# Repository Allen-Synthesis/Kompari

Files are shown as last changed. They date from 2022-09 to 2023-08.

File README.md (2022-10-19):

one
***
# Kompari
### A comparator module for Eurorack
  
***
### Features:
- 2 ±12V inputs, each with attenuverter
- Unipolar/Bipolar output switch
- 1 ±10V output, with attenuverter

Plug any CV or audio source into one of the two inputs, and it will be compared against the other.  

The output will be high (+10V) if input A is greater than input B.  

The output will be low (-10V if set to bipolar, 0V if set to unipolar) if input B is greater than input A.  

Both inputs have an attenuverter, and are both normalled to +12V, so with only one input, the value of input B can be controlled simply using the attenuverter as a ±10V voltage source.  
***
four
***
### Easy to DIY
The module has fairly few components, and is entirely through hole. It is also 'free hardware' so you can access all the design files in this repo, and check out the [Interactive Bill of Materials here!](https://htmlpreview.github.io/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)

***
### Patch Examples

#### PWM
While the concept may seem simple, the versatility of a comparator in Eurorack is far reaching.  
For example, feeding a triangle wave input to input A will result in a square wave output of the same wave, and input B (or simply the attenuverter normalled to +12) will act as PWM to that square wave. Plug the original triangle and this new PWM square wave into a crossfader/mixer and you now have a pretty modulatable waveshaper.  
  
#### Compressor
Another more complex case would be to run an audio source through an envelope follower, then into input A. Use input B to set a maximum voltage (volume), and when the volume of the audio (envelope follower voltage) goes above this voltage, the Kompari output should trigger an envelope generator which has a negative effect on the volume of a VCA on the original audio. You now have a slightly roundabout, but fully fledged compressor! The envelope generator's attack and decay controls are the response of the compressor, the VCA's unaltered input voltage (before subtracting the envelope) is the makeup gain, and the Kompari's input B is the threshold.  
  
As you can see, it's easy to get carried away with using a comparator module such as the Kompari, and the patches you can make are only limited by your imagination!

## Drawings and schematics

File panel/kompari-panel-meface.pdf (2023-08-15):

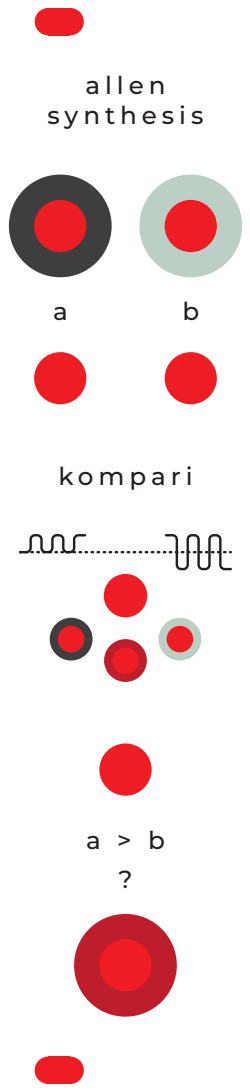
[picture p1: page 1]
kompari; allen synthesis

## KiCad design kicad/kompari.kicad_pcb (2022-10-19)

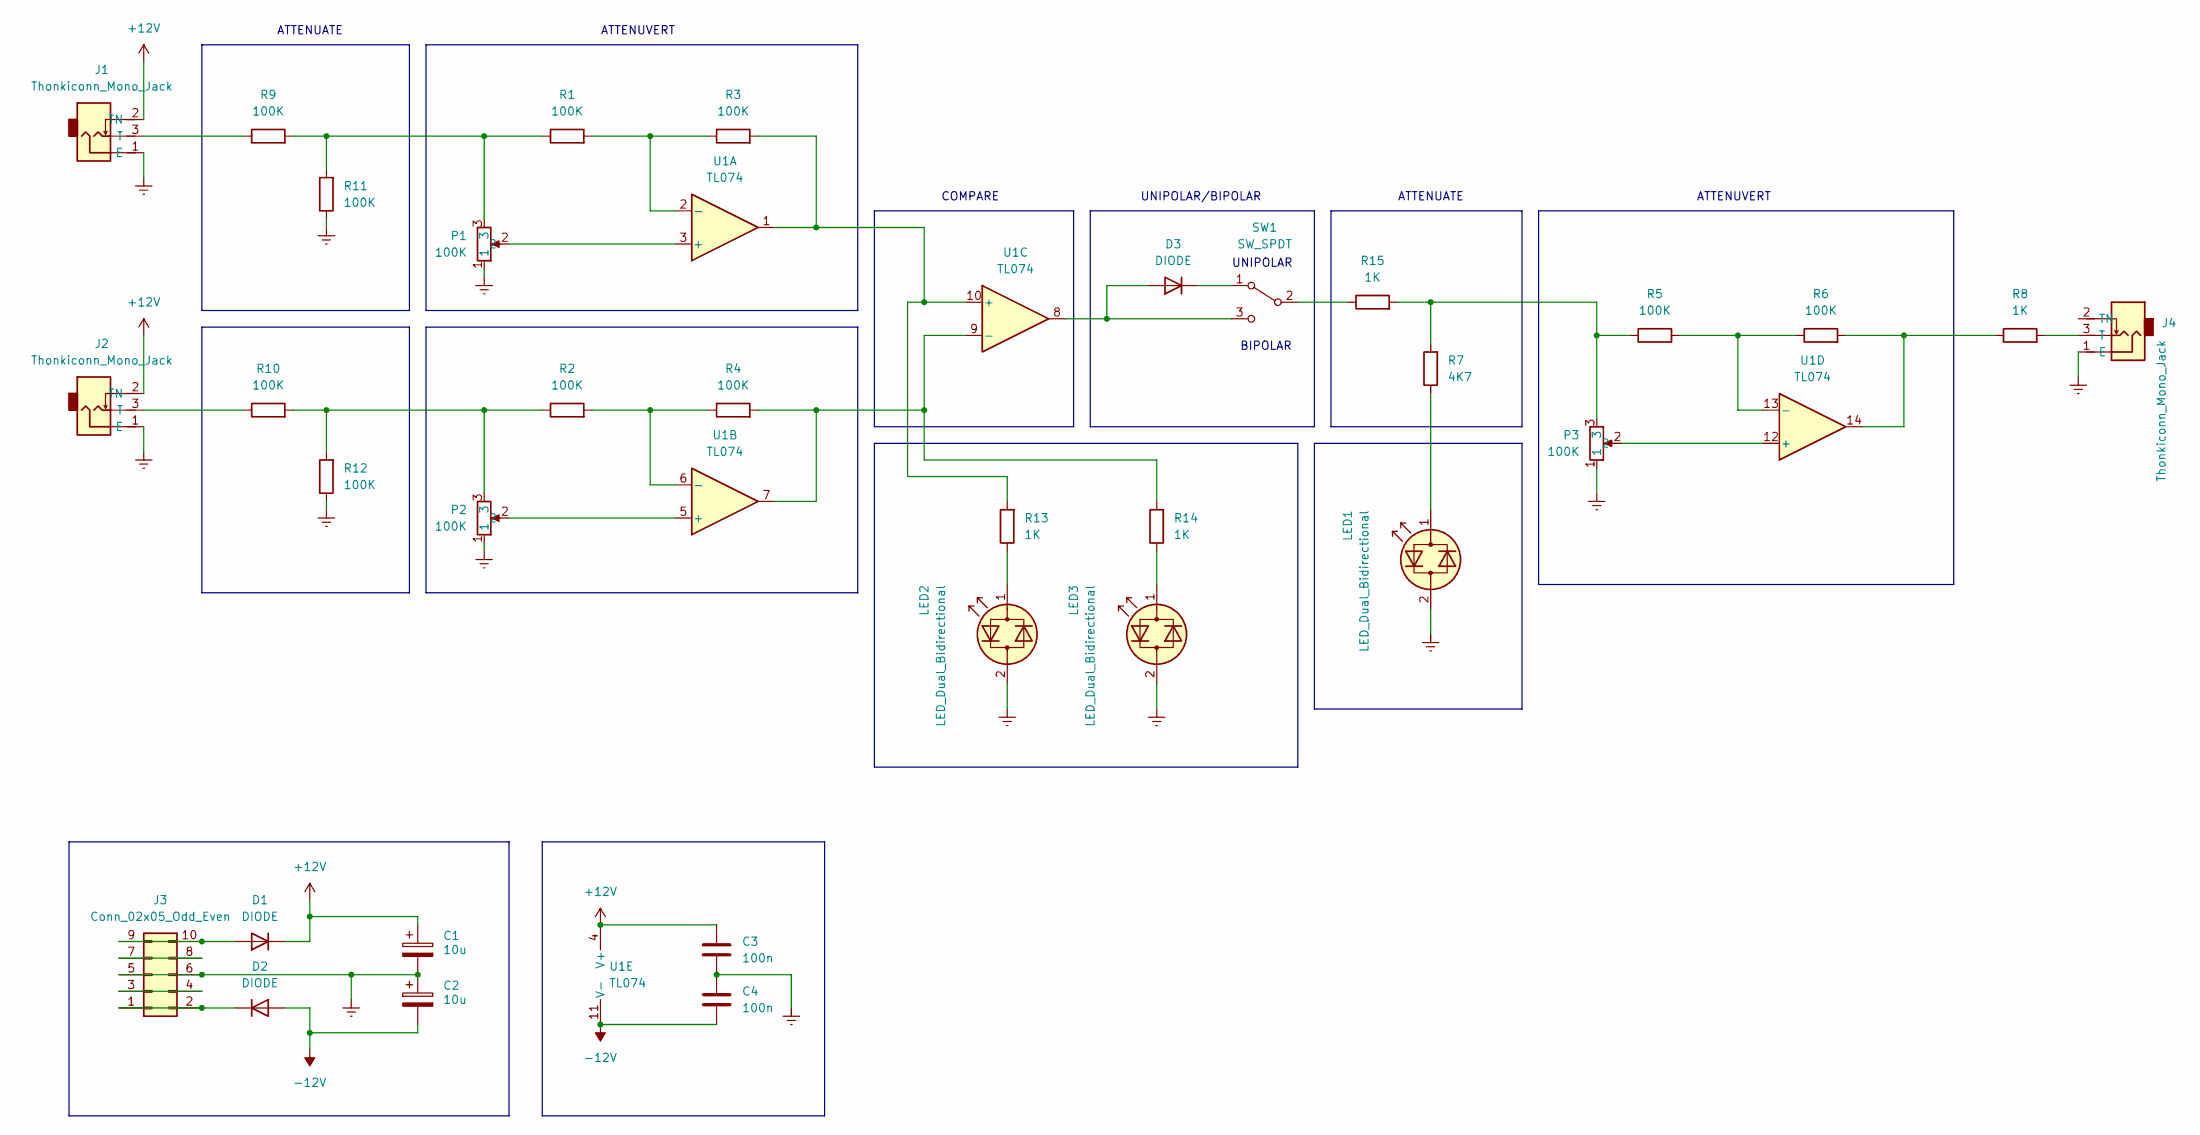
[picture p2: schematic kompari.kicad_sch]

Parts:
C1, C2: 10u; Capacitor Small Polarised
C3, C4: 100n; Capacitor Small Non-Polarised
D1, D2, D3: DIODE; Schottky Diode
J1, J2, J4: Thonkiconn_Mono_Jack; Thonkiconn Mono Jack
J3: Conn_02x05_Odd_Even; Eurorack Power Header
LED1, LED2, LED3: LED_Dual_Bidirectional; LED 3mm
P1, P2, P3: 100K; Potentiometer 9mm Vertical Linear Centred
R1, R2, R3, R4, R5, R6, R9, R10, R11, R12: 100K; Resistor 0.25W Through-Hole
R7: 4K7; Resistor 0.25W Through-Hole
R8, R13, R14, R15: 1K; Resistor 0.25W Through-Hole
SW1: SW_SPDT; Sub-Miniature Toggle Switch SPDT
U1: TL074; DIP-14 IC Socket

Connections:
+12V: C1.1, C3.1, D1.2 (K), J1.2 (TN), J2.2 (TN), U1.4 (V+)
-12V: C2.2, C4.2, D2.1 (A), U1.11 (V-)
Earth: C1.2, C2.1, C3.2, C4.1, J1.1 (E), J2.1 (E), J3.5, J3.6, J4.1 (E), LED1.2 (AK), LED2.2 (AK), LED3.2 (AK), P1.1, P2.1, P3.1, R11.1, R12.1
unnamed: D1.1 (A), J3.9, J3.10
unnamed: D2.2 (K), J3.1, J3.2
unnamed: D3.1 (A), SW1.3 (C), U1.8
unnamed: D3.2 (K), SW1.1 (A)
unnamed: J1.3 (T), R9.1
unnamed: J2.3 (T), R10.1
unnamed: J3.3, J3.4
unnamed: J3.7, J3.8
unnamed: J4.3 (T), R8.2
unnamed: LED1.1 (KA), R7.1
unnamed: LED2.1 (KA), R13.1
unnamed: LED3.1 (KA), R14.1
unnamed: P1.2, U1.3 (+)
unnamed: P1.3, R1.1, R9.2, R11.2
unnamed: P2.2, U1.5 (+)
unnamed: P2.3, R2.1, R10.2, R12.2
unnamed: P3.2, U1.12 (+)
unnamed: P3.3, R5.1, R7.2, R15.2
unnamed: R1.2, R3.1, U1.2 (-)
unnamed: R2.2, R4.1, U1.6 (-)
unnamed: R5.2, R6.1, U1.13 (-)
unnamed: R6.2, R8.1, U1.14
unnamed: R3.2, R13.2, U1.1, U1.10 (+)
unnamed: R4.2, R14.2, U1.7, U1.9 (-)
unnamed: R15.1, SW1.2 (B)

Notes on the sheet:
COMPARE
ATTENUATE
ATTENUVERT
UNIPOLAR
BIPOLAR
UNIPOLAR/BIPOLAR

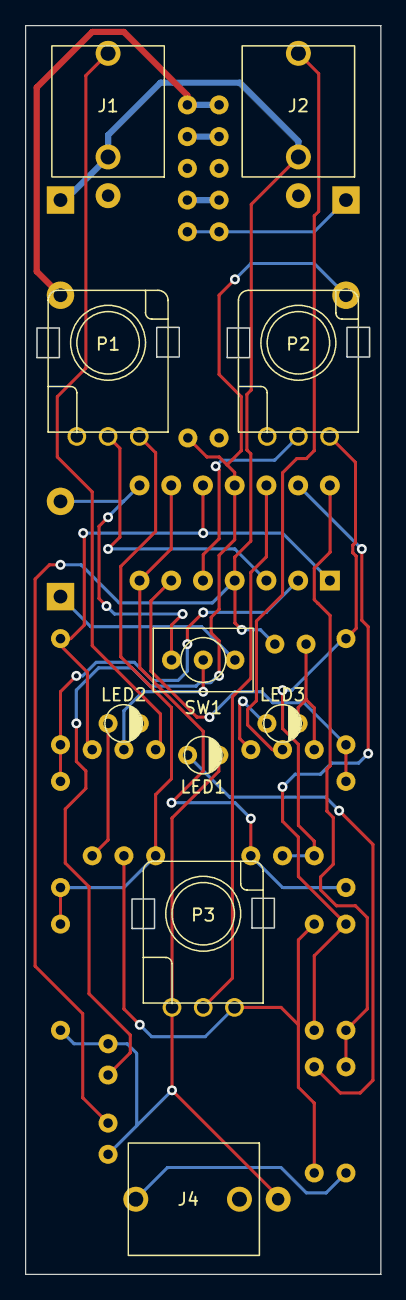
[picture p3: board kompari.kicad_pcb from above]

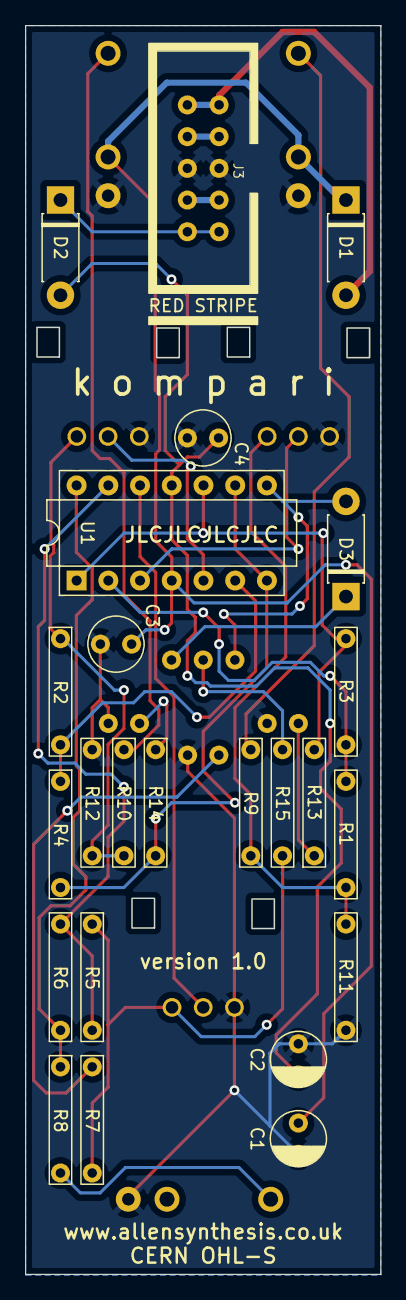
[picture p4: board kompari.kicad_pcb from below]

Board: 2 copper layers, 28.4 x 100.0 mm, 34 parts (24 on the bottom side), 28 nets.

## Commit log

2022-09-20 kicad save
    [kompari-B_Cu.gbr, kompari-B_Mask.gbr, kompari-B_Paste.gbr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]
2022-09-27 flow chart save
2022-09-27 Add BOM
2022-10-17 Save KiCad, create panel alternatives
    [kompari.kicad_sch]
2022-10-17 Optimise PCB trace spacing, fix switch
    The switch was previously the wrong way round, so left would be bipolar when it should be left for unipolar. This has been fixed as well as general increasing of spacing between traces
    [kompari.kicad_pcb]
2022-10-19 Add version number to PCB
    Add version number 1.0 to PCB
    Rotate C1 and C2 to not cover up website silkscreen
    Export Gerbers
    [kompari-B_Cu.gbr, kompari-B_Mask.gbr, kompari-B_Paste.gbr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]
2022-10-19 Update BOM link
2022-10-19 PCB improvements
    trace spacing
    wider traces for unprotected power lines
    potentiometer lug holes widened
    regenerate gerbers + bom
    [kompari-B_Cu.gbr, kompari-B_Mask.gbr, kompari-B_Paste.gbr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]
2023-08-15 add black kicad panel
    [kompari-panel.kicad_pcb]
2023-09-01 add black panel
    [kompari-panel.kicad_pcb]
2023-09-01 clean up
    [costs.xlsx]
2023-09-01 add panel gerber
    [kompari-B_Cu.gbr, kompari-B_Mask.gbr, kompari-B_Paste.gbr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]

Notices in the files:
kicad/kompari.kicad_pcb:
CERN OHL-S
